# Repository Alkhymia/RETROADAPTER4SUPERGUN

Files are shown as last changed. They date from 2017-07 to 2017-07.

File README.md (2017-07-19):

# RETROADAPTER4SUPERGUN

Uses the concept of Paul Quereshi's RetroAdapter, but with CommonGround-Output instead of USB.
Lets you connect a wide range of controllers to a supergun or JAMMA incl SNES, MD, SAT, PSX, N64 etc.

## Work in progress

Right now, only the pcb is provided. The Code for the RetroAdapterMod needs to be rewritten because the pins changed!
If you would like to help finish this project, any help is appreciated.

## PCB Specification

You can order the printed circuit board e.g. from itead.cc using the GERBER files that I provided.

```
50 x 50 mm
1.2 to 1.6 (recommended) mm Thickness
HASL
```

### Installing

* solder all components to the pcb
* Atmega µController needs to be flashed via ISP-PORT.
* connect your favourite joypad to either the DB9 or DB15 connector as shown in the original connection diagram. Bare in mind that the pins may have changed! A detailed new connection diagram will follow in the future.
* connect the output to your JAMMA or SUPERGUN setup.
* Play your arcade games with your favourite controller, such as the Sega Saturn or SNES joypad.

## Links

* Original source for "USB Retropad Adapter" from Bruno Freitas acquired via http://www.brunofreitas.com/node/41 (included for reference in folder original_Files)

* Original source for "Retro Adapter v2.1a" from Paul Qureshi acquired via http://denki.world3.net/retro_v2.html (incuded for reference in folder original_Files)

* https://github.com/rsn8887/RetroAdapterMod

## Built With

* [EAGLE](https://www.autodesk.de/products/eagle/overview)

## Contributing

Please read [CONTRIBUTING.md] for details on our code of conduct, and the process for submitting pull requests to us.

## Authors

* **Alex Schütz** - *Concept & PCB Design*
* **rsn8887** - *RetroAdapterMod*
* **Paul Qureshi** - *RetroAdapter*

See also the list of [contributors](https://github.com/your/project/contributors) who participated in this project.

## License

This project is licensed under the MIT License - see the [LICENSE.md](LICENSE.md) file for details

## Acknowledgments

* This is a work in progress.
* Don't mess with electronics if you don't know what you're doing!

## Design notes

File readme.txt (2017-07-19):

RETROADAPTER4SUPERGUN aka The Kraken

50 x 50 mm
1.2 to 1.6 (recommended) mm Thickness
HASL

Uses the concept of Paul Quereshi's RetroAdapter, but with CommonGround-Output instead of USB.
Lets you connect a wide range of controllers to a supergun incl SNES, MD, SAT, PSX, N64 etc.

Atmega µController needs to be flashed via ISP-PORT.

NOTE:
The Code for the RetroAdapterMod needs to be rewritten because the pins changed!

Links:
https://github.com/rsn8887/RetroAdapterMod

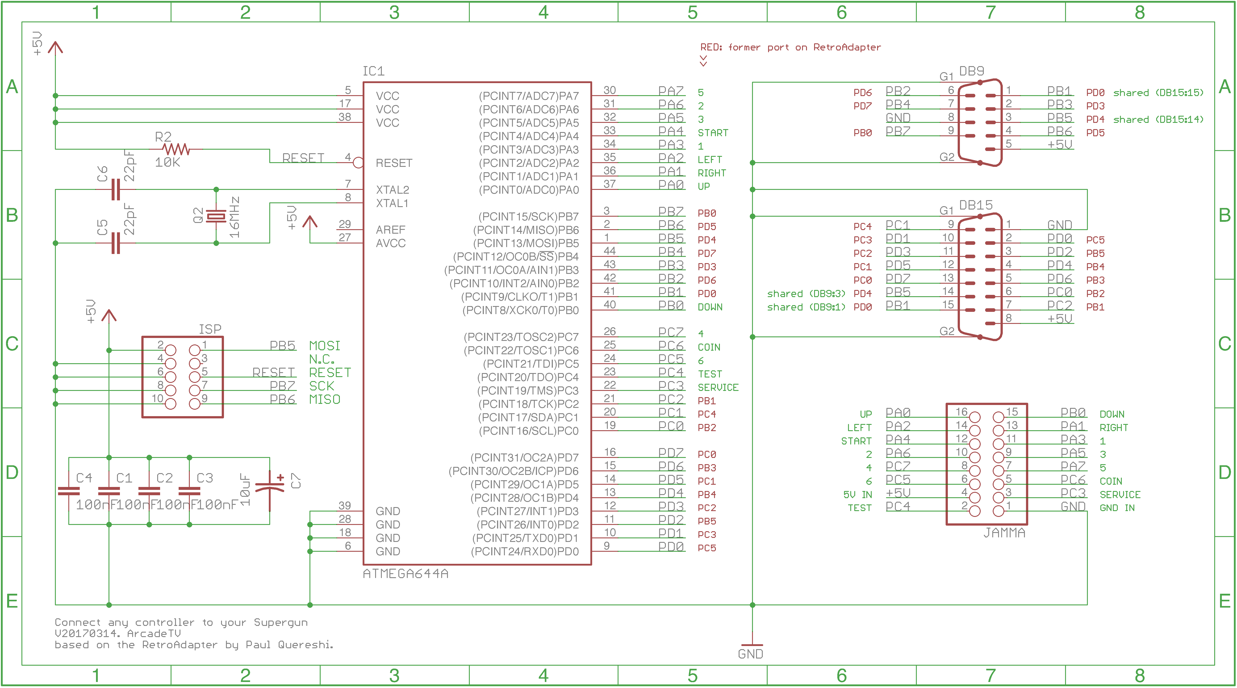
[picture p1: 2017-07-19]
IMAGES/schematic.png

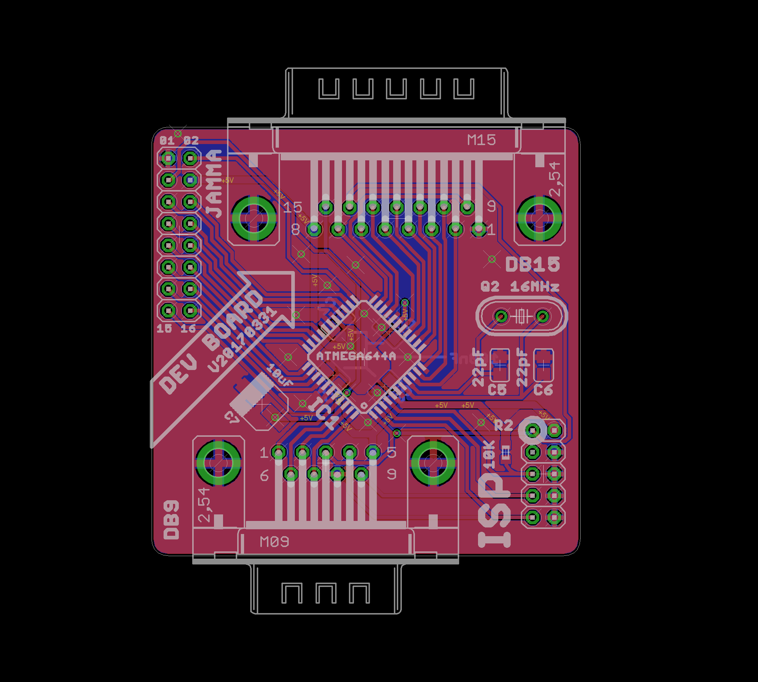
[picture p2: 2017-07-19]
IMAGES/brd.png

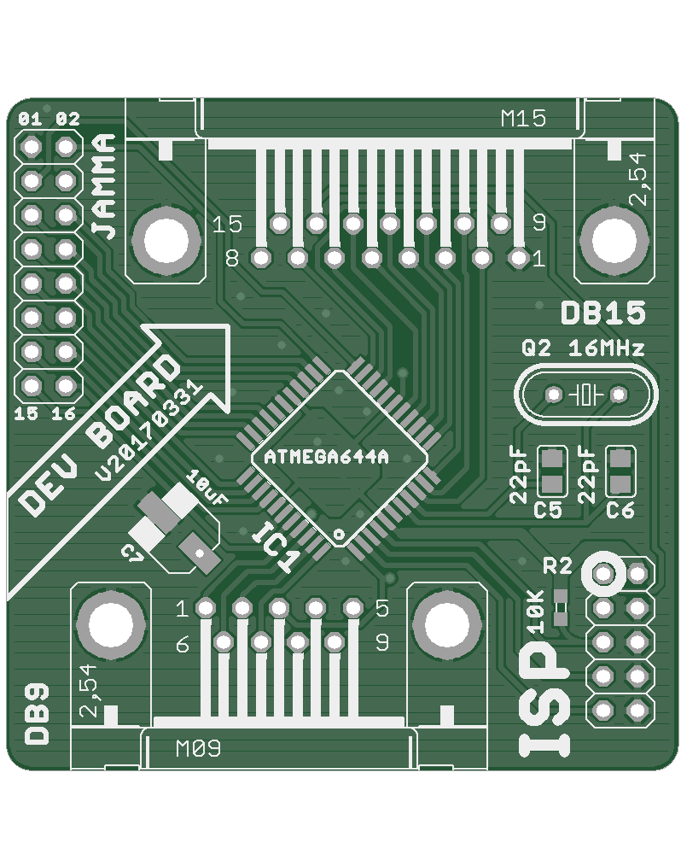
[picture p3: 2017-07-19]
IMAGES/top.png

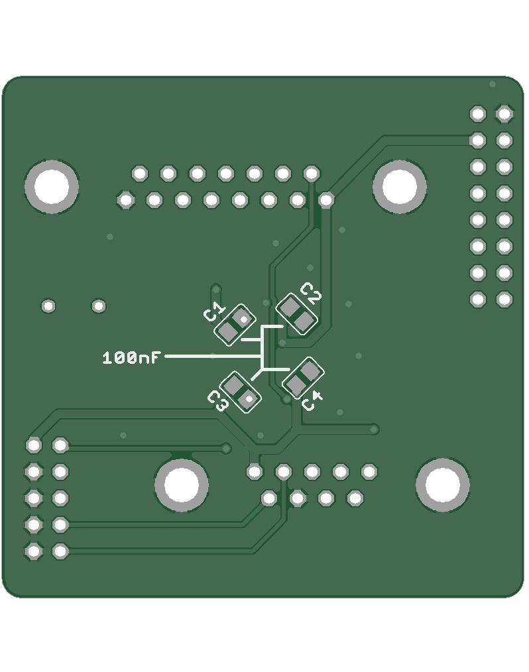
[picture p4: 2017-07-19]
IMAGES/bottom.png

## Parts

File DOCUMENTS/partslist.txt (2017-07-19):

Partlist

Exported from RetroAdapter2CommonGround.sch at 23.03.17 09:13

EAGLE Version 8.1.0 Copyright (c) 1988-2017 Autodesk, Inc.

Assembly variant: 

Part     Value          Device                            Package                           Library  Sheet

C1       100nF          C0805                             Z0805                             arcadetv 1
C2       100nF          C0805                             Z0805                             arcadetv 1
C3       100nF          C0805                             Z0805                             arcadetv 1
C4       100nF          C0805                             Z0805                             arcadetv 1
C5       22pF           C0805                             Z0805                             arcadetv 1
C6       22pF           C0805                             Z0805                             arcadetv 1
C7       10uF           EEEFPJ101UAR_PANASONIC_VFP-SERIES EEEFPJ101UAR_PANASONIC_VFP-SERIES arcadetv 1
DB9                     M09HP                             M09HP                             con-subd 1
DB15                    M15HP                             M15HP                             con-subd 1
IC1      ATMEGA644A     ATMEGA644A                        TQFP44                            arcadetv 1
ISP                     PINHD-2X5                         2X05                              pinhead  1
JAMMA                   PINHD-2X8                         2X08                              pinhead  1
Q2       15MHz          CRYSTALHC49S                      HC49/S                            crystal  1
R2       10K            R-US_R0603                        R0603                             rcl      1

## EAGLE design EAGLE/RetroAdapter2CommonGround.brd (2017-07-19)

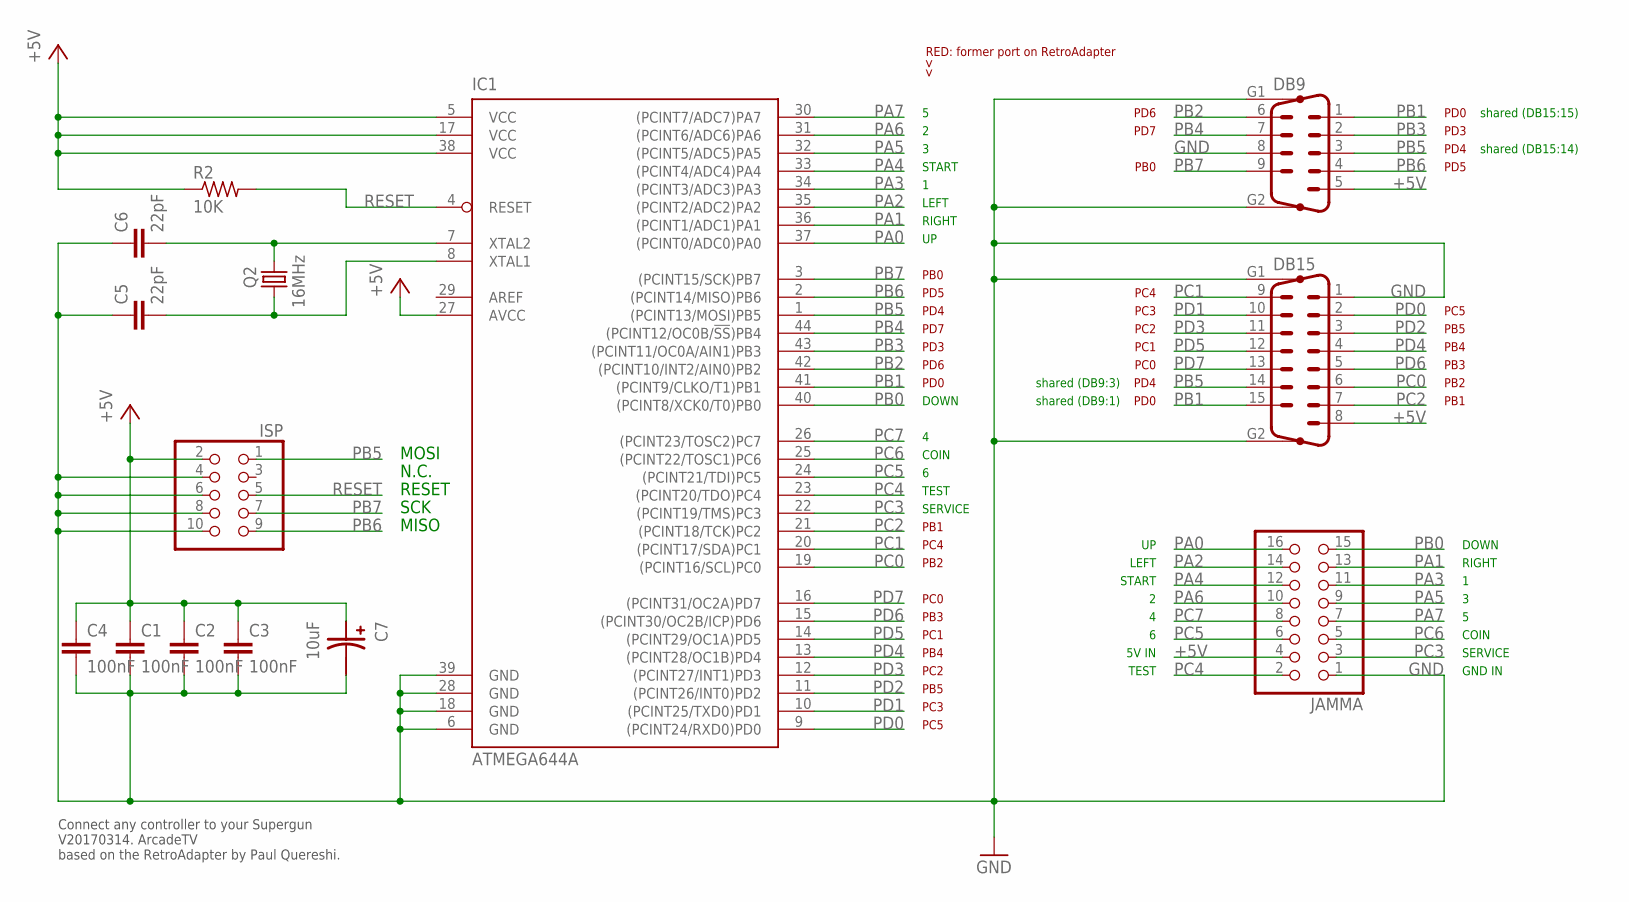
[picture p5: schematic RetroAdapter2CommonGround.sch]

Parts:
C1, C2, C3, C4: 100nF; Z0805
C5, C6: 22pF; Z0805
C7: 10uF; EEEFPJ101UAR_PANASONIC_VFP-SERIES
DB9: M09HP
DB15: M15HP
IC1: ATMEGA644A; TQFP44
ISP: PINHD-2X5; 2X05
JAMMA: PINHD-2X8; 2X08
Q2: 16MHz; HC49/S
R2: 10K; R0603

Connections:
+5V: C1.1, C2.1, C3.1, C4.1, C7.PLUS (+), DB9.5, DB15.8, IC1.5 (VCC), IC1.17 (VCC), IC1.27 (AVCC), IC1.38 (VCC), ISP.2, JAMMA.4, R2.1
GND: C1.2, C2.2, C3.2, C4.2, C5.1, C6.1, C7.MINUS (-), DB9.8, DB9.G1, DB9.G2, DB15.1, DB15.G1, DB15.G2, IC1.6 (GND), IC1.18 (GND), IC1.28 (GND), IC1.39 (GND), ISP.4, ISP.6, ISP.8, ISP.10, JAMMA.1
unnamed: C5.2, IC1.8 (XTAL1), Q2.1
unnamed: C6.2, IC1.7 (XTAL2), Q2.2
PA0: IC1.37 ((PCINT0/ADC0)PA0), JAMMA.16
PA1: IC1.36 ((PCINT1/ADC1)PA1), JAMMA.13
PA2: IC1.35 ((PCINT2/ADC2)PA2), JAMMA.14
PA3: IC1.34 ((PCINT3/ADC3)PA3), JAMMA.11
PA4: IC1.33 ((PCINT4/ADC4)PA4), JAMMA.12
PA5: IC1.32 ((PCINT5/ADC5)PA5), JAMMA.9
PA6: IC1.31 ((PCINT6/ADC6)PA6), JAMMA.10
PA7: IC1.30 ((PCINT7/ADC7)PA7), JAMMA.7
PB0: IC1.40 ((PCINT8/XCK0/T0)PB0), JAMMA.15
PB1: DB9.1, DB15.15, IC1.41 ((PCINT9/CLKO/T1)PB1)
PB2: DB9.6, IC1.42 ((PCINT10/INT2/AIN0)PB2)
PB3: DB9.2, IC1.43 ((PCINT11/OC0A/AIN1)PB3)
PB4: DB9.7, IC1.44 ((PCINT12/OC0B/!SS!)PB4)
PB5: DB9.3, DB15.14, IC1.1 ((PCINT13/MOSI)PB5), ISP.1
PB6: DB9.4, IC1.2 ((PCINT14/MISO)PB6), ISP.9
PB7: DB9.9, IC1.3 ((PCINT15/SCK)PB7), ISP.7
PC0: DB15.6, IC1.19 ((PCINT16/SCL)PC0)
PC1: DB15.9, IC1.20 ((PCINT17/SDA)PC1)
PC2: DB15.7, IC1.21 ((PCINT18/TCK)PC2)
PC3: IC1.22 ((PCINT19/TMS)PC3), JAMMA.3
PC4: IC1.23 ((PCINT20/TDO)PC4), JAMMA.2
PC5: IC1.24 ((PCINT21/TDI)PC5), JAMMA.6
PC6: IC1.25 ((PCINT22/TOSC1)PC6), JAMMA.5
PC7: IC1.26 ((PCINT23/TOSC2)PC7), JAMMA.8
PD0: DB15.2, IC1.9 ((PCINT24/RXD0)PD0)
PD1: DB15.10, IC1.10 ((PCINT25/TXD0)PD1)
PD2: DB15.3, IC1.11 ((PCINT26/INT0)PD2)
PD3: DB15.11, IC1.12 ((PCINT27/INT1)PD3)
PD4: DB15.4, IC1.13 ((PCINT28/OC1B)PD4)
PD5: DB15.12, IC1.14 ((PCINT29/OC1A)PD5)
PD6: DB15.5, IC1.15 ((PCINT30/OC2B/ICP)PD6)
PD7: DB15.13, IC1.16 ((PCINT31/OC2A)PD7)
RESET: IC1.4 (RESET), ISP.5, R2.2

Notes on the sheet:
MOSI
MISO
SCK
RESET
N.C.
Connect any controller to your Supergun V20170314. ArcadeTV based on the RetroAdapter by Paul Quereshi.
PD0
PD3
PD4
PD5
PD6
PD7
PB0
RED: former port on RetroAdapter
PC5
PB4
PB3
PB2
PB1
PC3
PC4
PB5
PC2
PC1
PC0
shared (DB9:3)
shared (DB9:1)
shared (DB15:15)
shared (DB15:14)
LEFT
START
5V IN
TEST
DOWN
RIGHT
COIN
SERVICE
GND IN

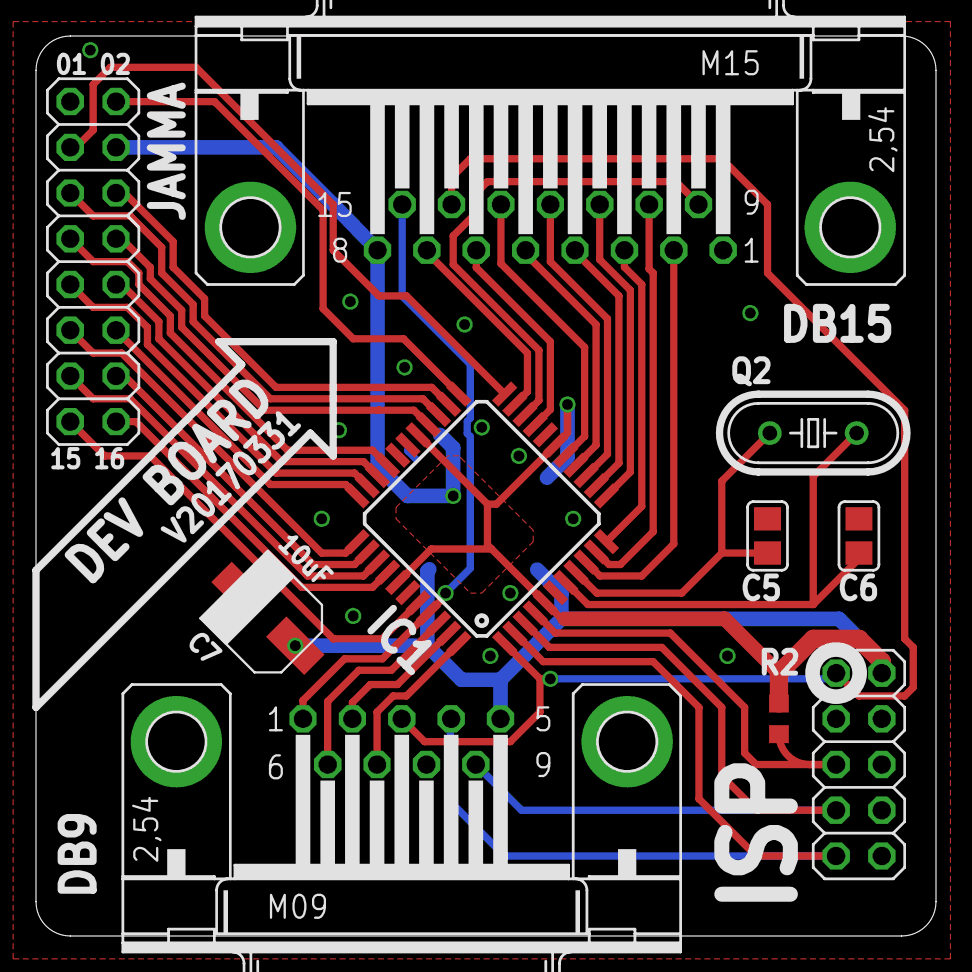
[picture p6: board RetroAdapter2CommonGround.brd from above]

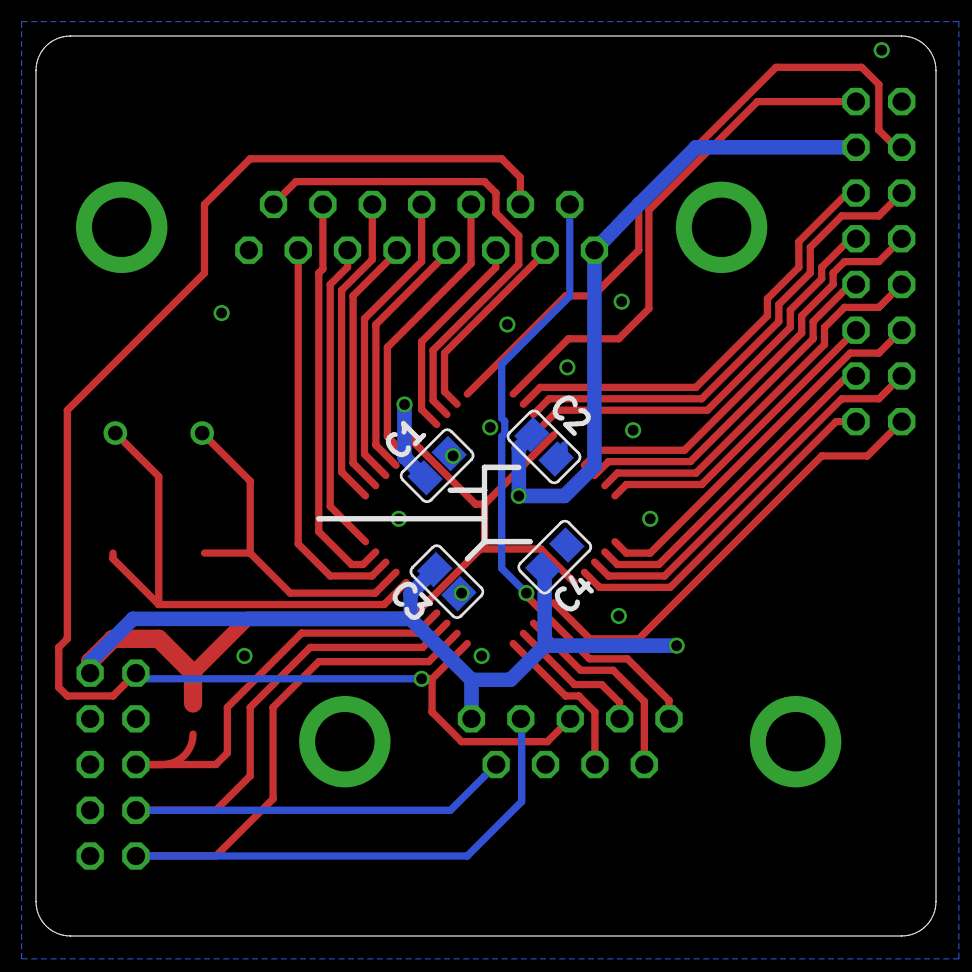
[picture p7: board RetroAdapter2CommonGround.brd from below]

Board: 2 copper layers, 50.0 x 50.0 mm, 14 parts (4 on the bottom side), 37 nets.
